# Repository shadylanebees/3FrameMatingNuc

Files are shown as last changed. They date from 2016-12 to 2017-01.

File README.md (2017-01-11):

# 3FrameMatingNuc
3D Printed Three (3) Frame Mating Nuc
(4 frame version available)

UNTESTED!! Developed over the 2016 winter, will be actually testing it in the spring/summer 2017

A 3 frame mating nuc that you can create with a 3D printer. The box, feeder tray, lid and the three frames use approx 550 grams (this will change as I make changes) (10% infill box, 20% infill all other parts) of filament. The frame size is small .. 1/3 of a normal Langstroth medium frames. With the spanners, the three frames can be taken out of the nuc and placed into a full medium Langstroth hive.

All parts are 3D printed, except one #4 x 3/8 (3mmx8) self-tapping (sheet metal, wood, cement) pan head screw to attach the entrance disk gate will be needed.

Created with OpenSCAD, you can change the size of the box, frames, etc. by changing the variables in each OpenSCAD file. Not quite parametric just yet but will be advancing with that goal in mind.

ASA filament, ASB filament, or a high temp/low warp PLA should work best. Except for ASA filament, you'll want to paint your prints to protect against UV.

**The box:** you can print the 3 or 4 frame version. 10% infill seems ok, might want to experiment with 15% infill but this will use more filament. The size of the box is larger and any mini-nuc that I'm aware of, the hope is that management needs and the chance of obsconding decrease.

**The entrance gate:** Use a screw mentioned above, the gate rotates from full open, venting only, or to the queen excluder

**The frames:** Printing the frames laying down requires supports but also creates the strongest frames. These are medium/western depth frames, using the spanners (see files), you can fit three of these in a normal hive to have the bees draw these out ahead of time.

**The feed tray:** Has a queen excluder to keep the queen away from the feed. Solid feed is better, ie: sugar, baker's fondant or candy (often times called fondant but it is not), or even pollen patties. The feed tray is optional. If you want to feed sugar syrup, then it would be best to print the top cover with a feed hole.

**The nuc cover:** Has option to be printed with a feed hole or not. With the feed hole, you can place a jar or other feeding container over the hive to feed the bees liquid feed (eg: 1:1 syrup).

**The spanners:** OK, maybe not the best name, a spanner in UK english is a wrench ... but this allows you to place the mini frames into a medium (or deep) box and have the bees draw the frames before using them in a mating nuc. See: https://github.com/shadylanebees/3FrameMatingNuc/blob/master/20161227_194710.jpg

_**This project has been placed in the Public Domain**_ as a thanks to all those very open, sharing and kind beekeepers all throughout the world, the open source software developers, including those who provide CAD software and slicing software, and to those who develop open source 3d printing machines. Kudos to you all! 

I would also like to encourage additional contributors to add to the project as they desire. I'm sure there's lots of ideas out there. If you want to contribute and are familiar with OpenSCAD, please let me know. Additional ideas that I have is a screened bottom, and other venting as needed (I live in a very moist climate)

DO NOTE: Working on this during the 2016/2017 winter - this HAS NOT been tried or tested as of yet. THIS IS EXPERIMENTAL
This is a work in progress. The picture may not represent the latest version.

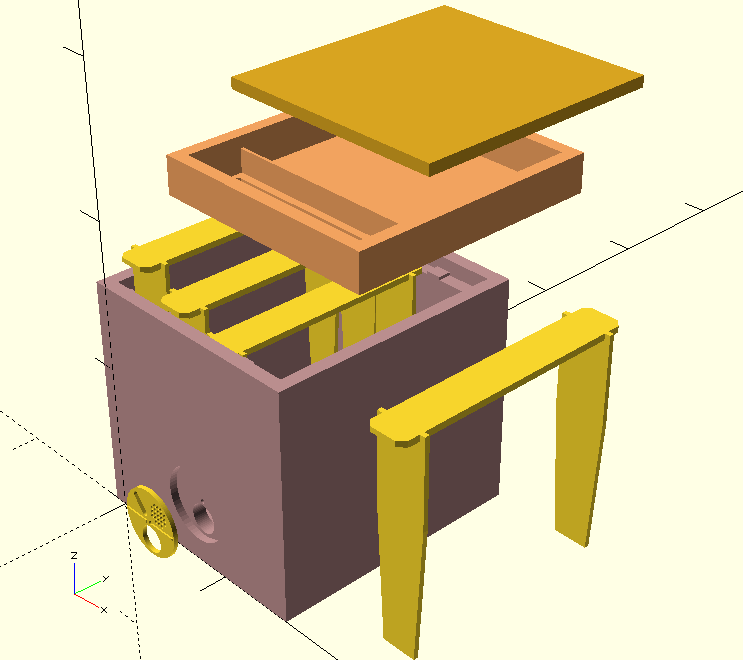
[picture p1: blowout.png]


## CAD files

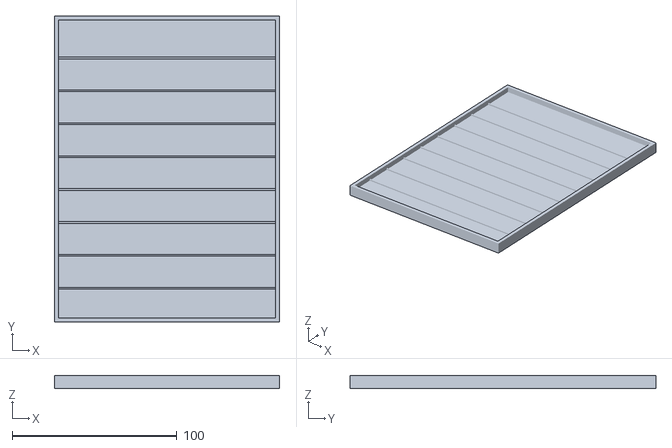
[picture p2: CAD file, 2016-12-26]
3 Frame Version/lid-3frame.stl
137.1 x 186.0 x 8.00

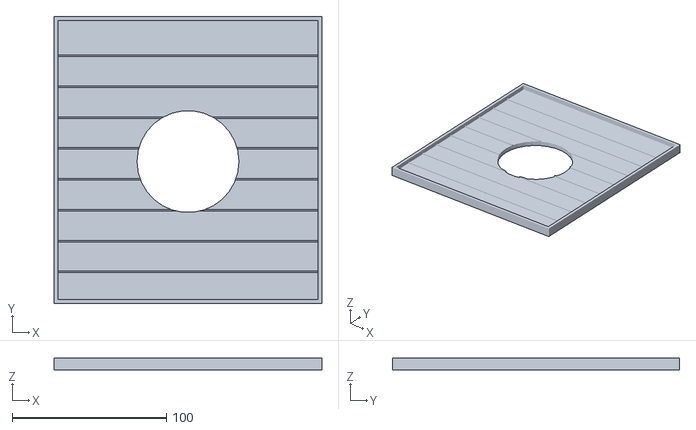
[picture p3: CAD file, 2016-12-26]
4 Frame Version/lid-w-hole.stl
173.6 x 186.0 x 8.00

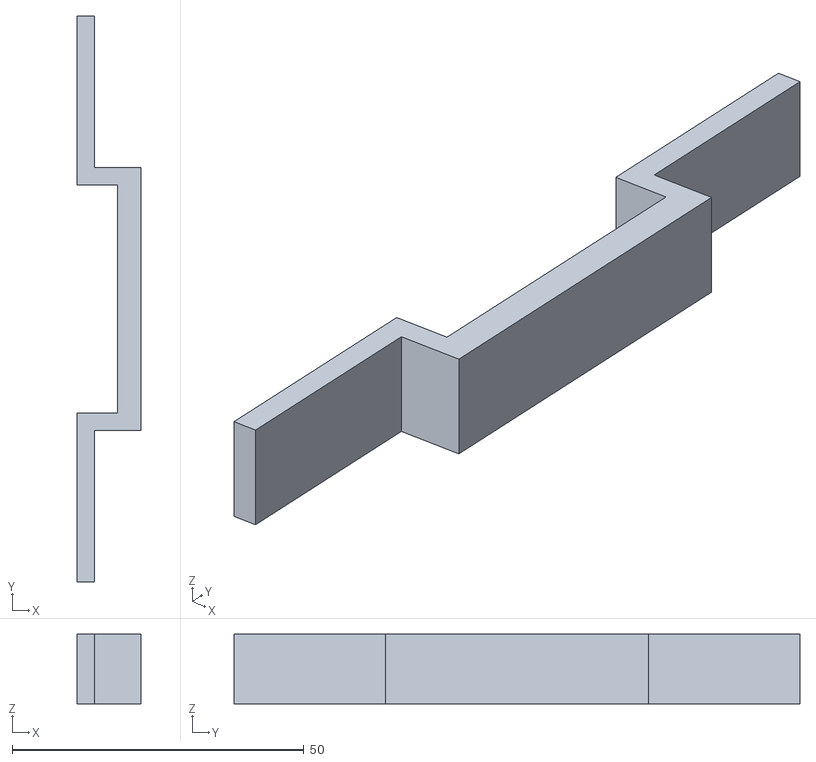
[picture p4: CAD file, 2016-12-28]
spanner.stl
11.0 x 97.0 x 12.0

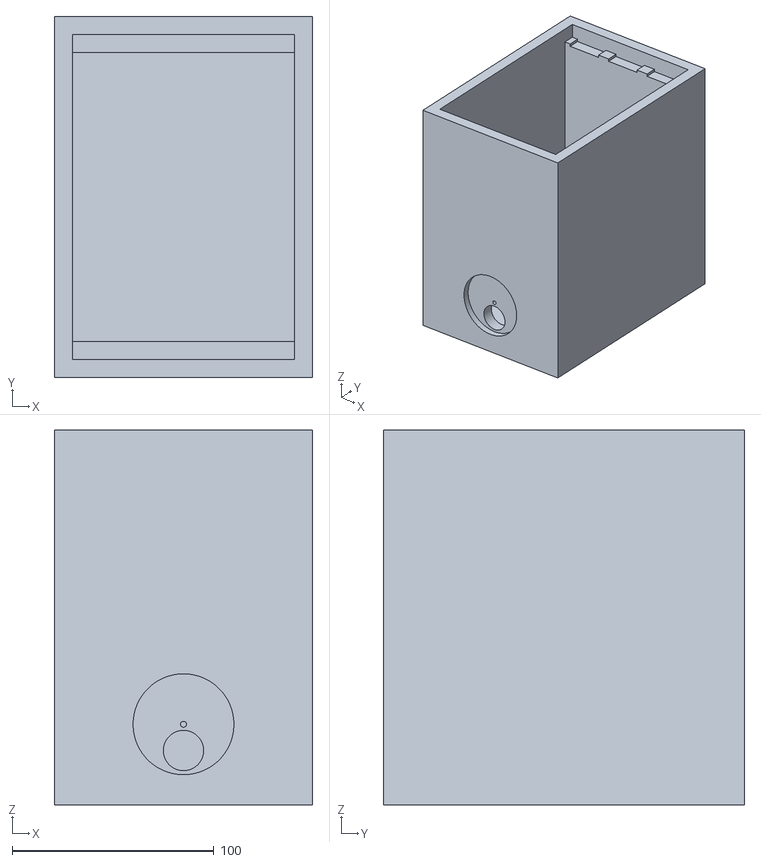
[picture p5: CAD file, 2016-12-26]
3 Frame Version/box-3frame.stl
128.1 x 179.0 x 185.8

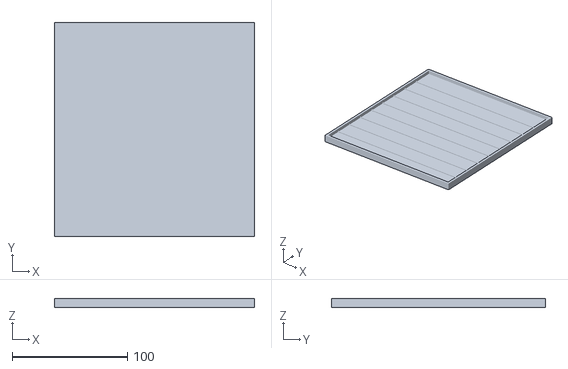
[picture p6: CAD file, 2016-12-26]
4 Frame Version/lid.stl
173.6 x 186.0 x 8.00

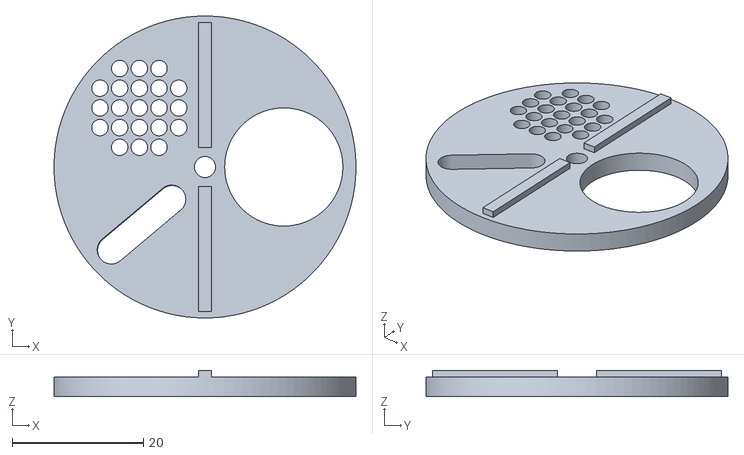
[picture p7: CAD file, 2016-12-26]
gate.stl
46.0 x 46.0 x 4.00

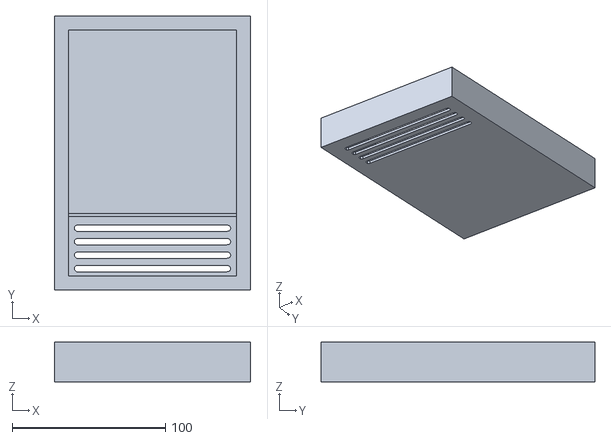
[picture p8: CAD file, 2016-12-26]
3 Frame Version/feed tray-3frame.stl
128.1 x 179.0 x 26.0

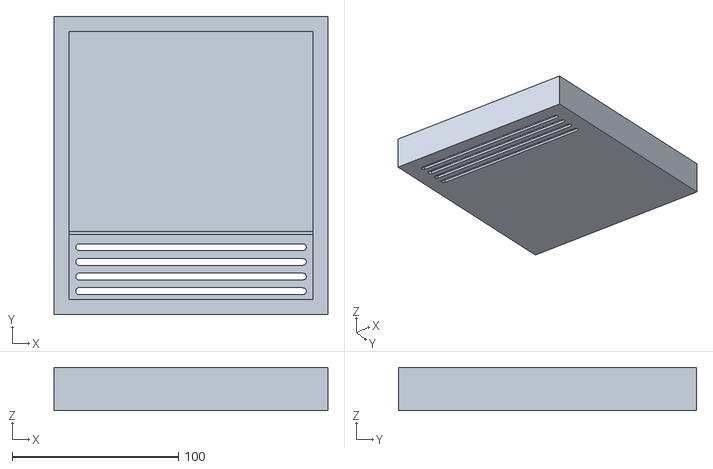
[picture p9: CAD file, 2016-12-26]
4 Frame Version/feed tray.stl
164.6 x 179.0 x 26.0

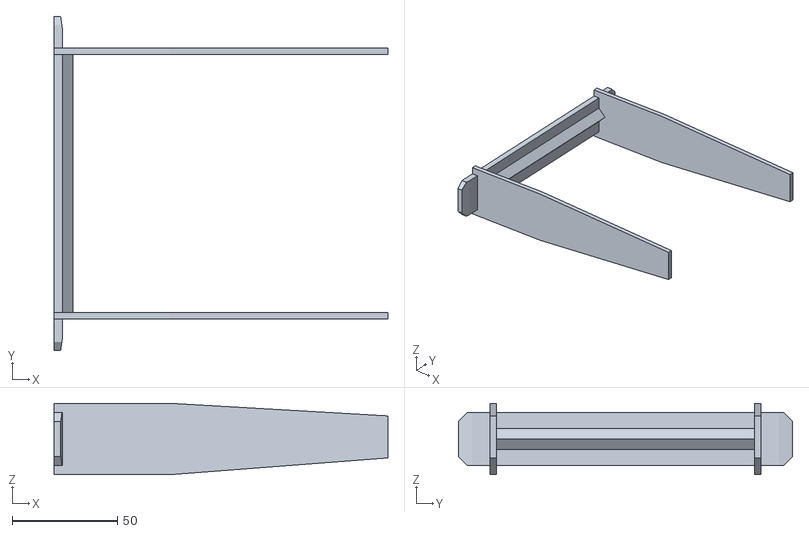
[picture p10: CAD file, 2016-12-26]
frame.stl
158.8 x 159.0 x 34.0

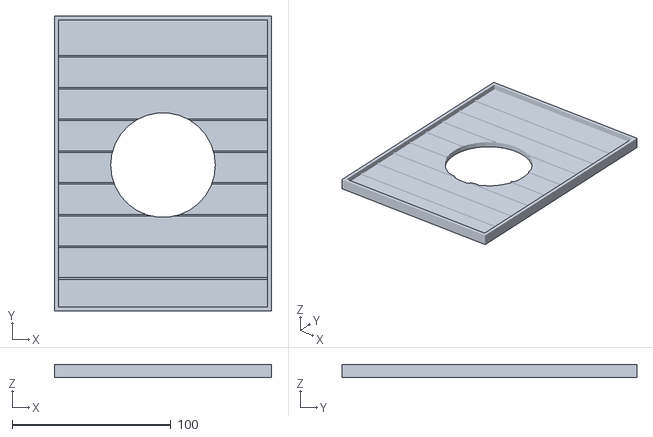
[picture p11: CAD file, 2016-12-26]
3 Frame Version/lid-w-hole-3frame.stl
137.1 x 186.0 x 8.00

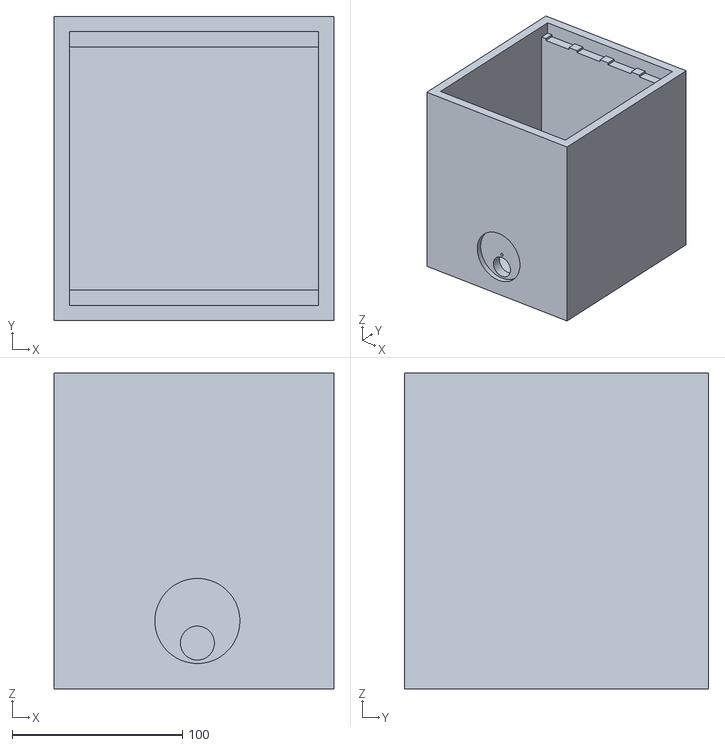
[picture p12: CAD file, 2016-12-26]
4 Frame Version/box.stl
164.6 x 179.0 x 185.8

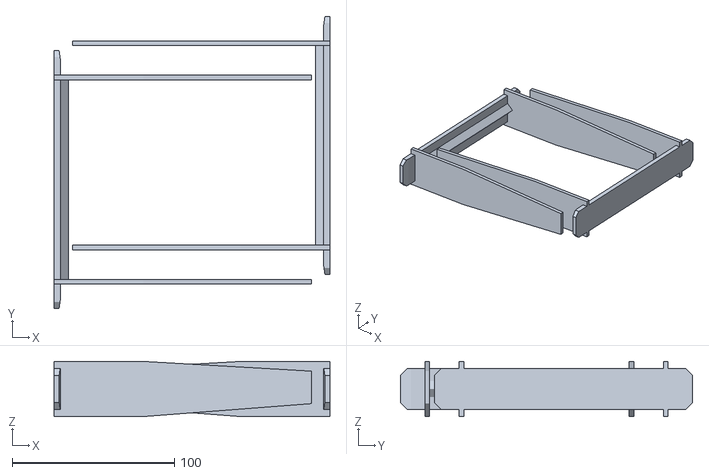
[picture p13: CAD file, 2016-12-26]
frames.stl
170.0 x 180.0 x 34.0

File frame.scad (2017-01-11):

x=25;
y=159; // see the box.scad framelength echo line and subtract 2 - this is the distance between the tapered top bar ends
z=4;


rotate([0,90,0]) frame();
//translate([170,180,0]) rotate([180,90,0]) frame();

module frame() {
rotate([0,0,0]) union() {
translate([-3.5,0,z]) rotate([0,180,0]) union() {
    quarter_frame(x,y,z);
    translate([x,0,0]) mirror([1,0,0]) quarter_frame(x,y,z);
    translate([0,y,0]) mirror([0,1,0]) quarter_frame(x,y,z);
    translate([0,y,0]) mirror([0,1,0]) translate([x,0,0]) mirror([1,0,0]) quarter_frame(x,y,z);
}

// legs
// medium frames are 158.8mm (rounded down)
translate([-33,18,0]) rotate([90,0,0]) tapered_leg();
translate([-33,y-15,0]) rotate([90,0,0]) tapered_leg();

// old straight legs
//translate([-32,15,3]) cube([32,2,158]);
//translate([-32,y-12,3]) cube([32,2,158]);

// comb bridge
translate([(-32/2-5),16,4]) rotate([135,0,90]) prism(y-6-14-6-8,7,12);
}
}

module quarter_frame(x,y,z) {
    difference() {
        cube([x/2,y/2,z]);
        translate([-5,2,0])  rotate([0,0,-45]) color("red") cube([10,5,6]);
        translate([0,-1,-4])  rotate([-8,0,0]) color("red") cube([x,10,5]);
    }
}

module prism(l, w, h){
       polyhedron(
               points=[[0,0,0], [l,0,0], [l,w,0], [0,w,0], [0,w,h], [l,w,h]],
               faces=[[0,1,2,3],[5,4,3,2],[0,4,5,1],[0,3,4],[5,2,1]]
               );
}

module tapered_leg() {
linear_extrude(height = 3, convexity = 3) polygon([[0,0],[34,0],[34,55],[26,158.8],[6,158.8],[0,55]],[[0,1,2,3,4,5]]);
}    

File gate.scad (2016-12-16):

/*
Open Mating Nuc, released to the Public Domain by Robert Niles
*/

$fn=100;

//translate([0,0,2.9]) {
//rim();
//}
bee_gate();

module bee_gate(){
    
    difference() {
       // gate area
       color("green") {
           cylinder(h=3, r=23);
       }
     
       // create the entrance hole
       translate([12,0,-1]) {
            rotate([0,0,0]) {
                color("blue") {
                cylinder(h=5, r=9);
               }
            }
        }
        
        // draw the vent holes
        vents();
        
        // screw hole
        translate([0,0,-1]) {
            rotate([0,0,0]) {
                color("teal") {
                cylinder(h=5, d=3.2);
               }
            }
        }
        
        // queen excluder
        translate([-5,-5,-.5]) {
            rotate([2,0,220]) {
                color("red") {
                    hull() {
                        cylinder(d=4.3,d=4.3,4);
                        translate([12,0,0]) {
                            cylinder(d=4.3,d=4.3,4);
                        }
                    }
                }
            }
        }
     
  
             
    } // end difference
    
    // handles
    translate([1,3,2]) {   
        rotate([0,0,90]) {
            color("blue") {
                cube([19,2,2]);
            }
        }
    }
    translate([-1,-3,2]) {
        rotate([0,0,270]) {
            color("blue") {
                cube([19,2,2]);
            }
        }
    }
}
     
// vents
module vents() {   
    for (a =[7:3:13]) {
        translate([-a,3,0]) vent_hole();
    }

    for (a =[4:3:16]) {
        translate([-a,6,0]) vent_hole();
    }
    
    for (a =[4:3:16]) {
        translate([-a,9,0]) vent_hole();
    }
    
    for (a =[4:3:16]) {
        translate([-a,12,0]) vent_hole();
    }
    
    for (a =[7:3:13]) {
        translate([-a,15,0]) vent_hole();
    }
}

module vent_hole() {
    color("pink") cylinder(h=5, r=1.25);   
}

// I'm not sure I see a need for this...
module rim() {
    difference() {
       // gate area
       color("violet") {
           cylinder(h=1, r=23);
       }
       translate([0,0,0]) {
      color("blue") {
          cylinder(h=1, r=22);
      }
  }
}

}

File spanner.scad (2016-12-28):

linear_extrude(height = 12) {
    difference() {
        // prob better to draw this with polygon ..but....
        square([11,97.05]);
        color("green") translate([3,0,0]) square(26);
        color("green") translate([3,71.05,0]) square(26);
        color("green") translate([-32.05,29,0]) square(39.05);
    }
}

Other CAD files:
3 Frame Version/box-3frame.scad
4 Frame Version/box.scad
4 Frame Version/feed tray.scad
4 Frame Version/lid.scad

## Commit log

2016-12-16 dimensional changes
    Body of the mating nuc
    [box.scad]
2016-12-16 Update feed tray.scad
    Feed tray for the mating nuc
    [feed tray.scad]
2016-12-16 Update frame.scad
    frames, print 4
    [frame.scad]
2016-12-16 nuc lid
    [lid.scad]
2016-12-19 3 Frame version
    The 3 frame version of the 4 frame box.scad
    [box-3frame.scad]
2016-12-19 lid with hole
    Lid with a hole that a jar of sugar water can be used to feed instead of the feeder tray.
    [lid-w-hole.scad]
2016-12-19 With or without jar hole
    Variable to add a hole to place a top jar feeder instead of using the feed tray.
    [lid.scad]
